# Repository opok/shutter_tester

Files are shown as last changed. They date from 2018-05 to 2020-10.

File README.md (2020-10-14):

# shutter_tester
Arduino camera focal plane shutter speed tester

Circuit uses Arduino Nano 5V and its internal pullup resistor.
2 phototransistors are connected between D2 and GND, and second between D3 and GND.
D2 and D3 because hardware interrupts are available on those pins.

Digital input pin is set to HIGH, but when light hits phototransistor, 
that pulls the volatage of the pin to the ground so reading of the pin returns LOW.
I use interrupts to capture the exact moment the pin is pulled low or goes high.
In interrupt handler routine only the microsecond time is saved.

1604 a.k.a. 16 x 4 character LCD is connected via I2C by 4 wires: SDA, SCL and power supply 5V and GND.

The output on LCD shows exposure time for each sensor as well as curtain travel time of curtain extrapolated to 36mm frame witdth.
My sensors (phototransistors) are 30x20mm apart, positioned diagonally for measuring horizontal as well as vertical shutter,
so the travel time is multiplied by 1.2 to give result for 36mm or 24mm travel.

uses https://github.com/JChristensen/Timer v2 library
https://bitbucket.org/fmalpartida/new-liquidcrystal for LCD via I2C

To find the address of your I2C LCD, use I2C scanner from https://github.com/todbot/SoftI2CMaster (also part of New Liquid Crystal library)

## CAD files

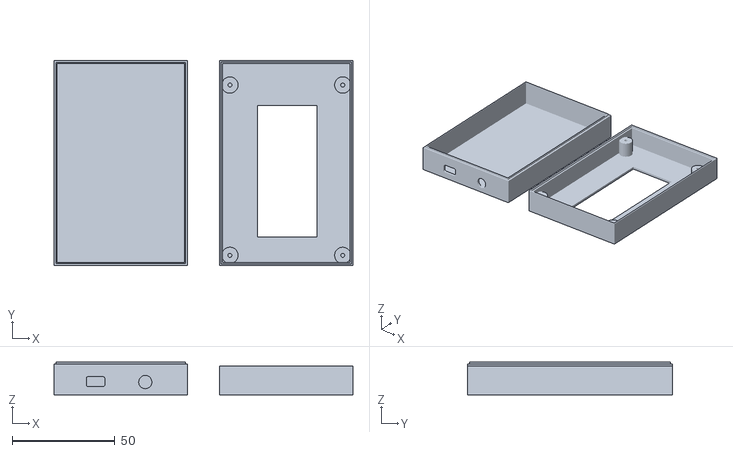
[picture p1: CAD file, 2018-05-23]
Shutter tester box for LCD + Arduino Nano.stl
145.8 x 100.0 x 16.0

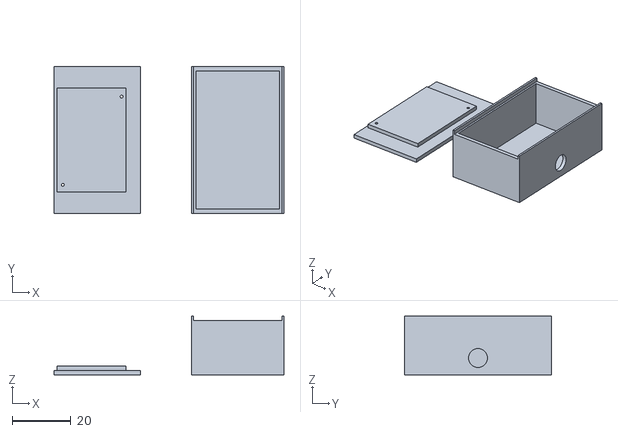
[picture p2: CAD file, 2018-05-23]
Shutter tester probe with own box.stl
78.2 x 50.0 x 20.0

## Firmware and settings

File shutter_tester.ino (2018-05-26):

/*
 * @author Ondrej Pok
 * @version 2.2
 *
 * Arduino camera focal plane shutter speed tester
 *
 * Circuit uses Arduino Nano 5V and its internal pullup resistor.
 * 2 phototransistors are connected between D2 and GND, and second between D3 and GND.
 * D2 and D3 because hardware interrupts are available on those pins.
 *
 * Digital input pin is set to HIGH, but when light hits phototransistor, 
 * that pulls the volatage of the pin to the ground so reading of the pin returns LOW.
 * I use interrupts to capture the exact moment the pin is pulled low or goes high.
 * In interrupt handler routine only the microsecond time is saved.
 *
 * 1604 a.k.a. 16 x 4 character LCD is connected via I2C by 4 wires: SDA, SCL and power supply 5V and GND.
 *
 * The output on LCD shows exposure time for each sensor as well as curtain travel time from sensor 1 to sensor 2.
 * My sensors (phototransistors) are 30x20mm apart, positioned diagonally for measuring horizontal as well as vertical shutter,
 * so the travel time is multiplied by 1.2 to give result for 36mm or 24mm travel.
 *
 * uses https://github.com/JChristensen/Timer v2 library
 * https://bitbucket.org/fmalpartida/new-liquidcrystal for LCD via I2C
 *
 * To find the address of your I2C LCD, use I2C scanner from https://github.com/todbot/SoftI2CMaster (also part of New Liquid Crystal library)
 */

#include <avr/io.h>
#include <avr/interrupt.h>
#include <Wire.h>
#include <LCD.h>
#include <Timer.h>
#include <LiquidCrystal_I2C.h>

#define SENSOR_1 2
#define SENSOR_2 3

#define I2C_ADDR       0x3f
#define BACKLIGHT_PIN  3
#define En_pin  2
#define Rw_pin  1
#define Rs_pin  0
#define D4_pin  4
#define D5_pin  5
#define D6_pin  6
#define D7_pin  7

#define ONE_SECOND 1000000

#define HOLE_X_DISTANCE 30 // keep in mind that hole_Y_distance = hole_X_distance * 24 / 36
#define HOLE_DIAMETER 1.0

// I measured the travel using simpler probe connected to PC sound card and Audacity
// and the tester was giving lot shorter times, so this constant is to compensate.
// Ideally this would be adjusted after comparing results with factory calibrated shutter tester.
#define TRAVEL_CORR_COEF 1.15

// see computation of exposure1 in onDataReady()
// This is to compensate for the simple fact that the transistor 
// doesn't open as soon as curtain edge crosses edge of hole.
// It takes a little bit of opening of the hole to let through enough light 
// to open the transistor - let's say 20% of hole diameter. Same for closing curtain
// the transistor closes before the closing curtain completely closes the hole 
// when the amount of light drops enough. This again may be 20%. So we only need 
// to subtract 60% of the hole diameter from raw exposure measurement.
#define HOLE_SIZE_CORR_COEF 0.6

// if you flip the probe, so S2 is exposed before S1 (S2->S1)
// and the average of several measurements significantly differ from the position (S1->S2)
// then one of these values needs to be adjusted
#define S1_CORR_COEF 1.0
#define S2_CORR_COEF 1.0


LiquidCrystal_I2C lcd (I2C_ADDR,En_pin,Rw_pin,Rs_pin,D4_pin,D5_pin,D6_pin,D7_pin);

// data storage
// 1st item is when sensor was uncovered and light started hitting the phototransistor
// 2nd item is when sensor was covered again
volatile unsigned long s1[2] = {0, 0}, s2[2] = {0, 0};

volatile bool dataReady = false;

Timer timer;


void resetMeasuredData(void *context) {
  Serial.println("resetting data...");
  s1[0] = 0;
  s1[1] = 0;
  s2[0] = 0;
  s2[1] = 0;
  dataReady = false;
  initInterrupts();
}

void printRightAlignedMs(int row, unsigned long microseconds) {
  int whole = microseconds/1000; // whole part from microseconds to miliseconds
  int decimal = (microseconds % 1000) / 10; // 2 decimal digits
  if(whole > 0)
    lcd.setCursor(10 - floor(log10(whole)), row); // how many digits ?
  else
    lcd.setCursor(10, row); // e.g. 0.12ms
  lcd.print(whole, DEC);
  lcd.print('.');
  if(decimal < 10) lcd.print('0');
  lcd.print(decimal, DEC);
  lcd.print("ms");
}

void printExposure(int row, String description, unsigned long exposure) {
  lcd.setCursor(0, row);
  lcd.print("                "); // clear
  lcd.setCursor(0, row);
  lcd.print(description); lcd.print(" ");

  if(exposure < ONE_SECOND) {
    lcd.print("1/"); lcd.print(round(1.0/((double)exposure/ONE_SECOND)), DEC);  
  }
  printRightAlignedMs(row, exposure);
}

void printTravel(int row, String description, unsigned long travel) {
  lcd.setCursor(0, row);
  lcd.print("                ");
  lcd.setCursor(0, row);
  lcd.print(description); lcd.print(" ");

  printRightAlignedMs(row, travel);
}

void onDataReady() {
  Serial.println("onDataReady");
  unsigned long exposure1, exposure2, travel1, travel2, exp1raw, exp2raw, travel1raw, travel2raw;

  travel1raw = max(s1[0], s2[0]) - min(s1[0], s2[0]);
  travel2raw = max(s2[1], s1[1]) - min(s2[1], s1[1]);
  // sensors approx. 20x30mm apart, extrapolate to 24 or 36mm
  travel1 = TRAVEL_CORR_COEF * (36/HOLE_X_DISTANCE) * travel1raw;
  travel2 = TRAVEL_CORR_COEF * (36/HOLE_X_DISTANCE) * travel2raw;

  exp1raw = s1[1] - s1[0];
  exp2raw = s2[1] - s2[0];
  // for measuring exposure the light starts to shine on sensor 
  // when the opening curtain crosses the left edge of the hole
  // but we measure the end of exposure when the light stops shining on the sensor 
  // and that is after closing curtain crosses right edge of the hole
  // Therefore to compensate for the size of the sensor hole
  // we need to subtract the time that takes the closing curtain to travel across the hole
  exposure1 = S1_CORR_COEF * (exp1raw - HOLE_SIZE_CORR_COEF * HOLE_DIAMETER * travel2 / 36);
  exposure2 = S2_CORR_COEF * (exp2raw - HOLE_SIZE_CORR_COEF * HOLE_DIAMETER * travel2 / 36);

  Serial.print("Exposure S1 "); Serial.println(exposure1);
  Serial.print("Exposure S2 "); Serial.println(exposure2);
  Serial.print("Travel opening "); Serial.println(travel1);
  Serial.print("Travel closing "); Serial.println(travel2);
  
  printExposure(0, "E1", exposure1);
  printExposure(1, "E2", exposure2);
  printTravel(2, "Open", travel1);
  printTravel(3, "Close", travel2);

  timer.after(1000, resetMeasuredData, (void*)0);
}

void s1_down() {
  unsigned long measuredValue = micros();
  if(dataReady) { return; }
  if(s1[0] == 0){
    s1[0] = measuredValue;
  }
  detachInterrupt(digitalPinToInterrupt(SENSOR_1));
  attachInterrupt(digitalPinToInterrupt(SENSOR_1), s1_up, RISING);

  //timer to stop waiting for more signals and to reset interrupts after ~2 seconds
  timer.after(2000, resetMeasuredData, (void*)0);
}

void s1_up() {
  unsigned long measuredValue = micros();
  if(dataReady) { return; }
  if(s1[1] == 0)
    s1[1] = measuredValue;
  detachInterrupt(digitalPinToInterrupt(SENSOR_1));
}

void s2_down() {
  unsigned long measuredValue = micros();
  if(dataReady) { return; }
  if(s2[0] == 0)
    s2[0] = measuredValue;
  detachInterrupt(digitalPinToInterrupt(SENSOR_2));
  attachInterrupt(digitalPinToInterrupt(SENSOR_2), s2_up, RISING);
}

void s2_up() {
  unsigned long measuredValue = micros();
  if(dataReady) { return; }
  if(s2[1] == 0)
    s2[1] = measuredValue;
  detachInterrupt(digitalPinToInterrupt(SENSOR_2));
}

void initInterrupts() {
  detachInterrupt(digitalPinToInterrupt(SENSOR_1));
  detachInterrupt(digitalPinToInterrupt(SENSOR_2)); 
  EIFR = 0x03; // reset interrupt register
  attachInterrupt(digitalPinToInterrupt(SENSOR_1), s1_down, FALLING);
  attachInterrupt(digitalPinToInterrupt(SENSOR_2), s2_down, FALLING);
}



void setup()
{
  Serial.begin(9600);
  Serial.println("setting up...");
  
  lcd.begin(16,4);
  lcd.setBacklightPin(BACKLIGHT_PIN,NEGATIVE);

  // set input pins HIGH
  digitalWrite(SENSOR_1, HIGH);
  digitalWrite(SENSOR_2, HIGH);
  
  initInterrupts();
}

void loop()
{
  timer.update();
  
  if(!dataReady && s1[0] != 0 && s1[1] != 0 && s2[0] != 0 && s2[1] != 0) {
    dataReady = true;
    onDataReady();
  }
}

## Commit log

2018-05-23 performance tweak and improved LCD output
    - remove serial print from inside of interrupt handler
    - improve LCD output - now LCD uses 4 rows to display these values:
    - exposure of sensor 1 as fraction and in miliseconds e.g. "E1 1/50 20.00ms"
    - travel time of opening and closing curtain e.g. "Open 12.34ms"
2018-05-23 revert back the file description comment
    [shutter_tester.ino]
2018-05-23 add 3D model files for the boxes
    [Shutter tester box for LCD + Arduino Nano.stl, Shutter tester probe with own box.stl]
2018-05-23 fix display of exposure < 1ms
    [shutter_tester.ino]
2018-05-26 add correction coeficient constants
    [shutter_tester.ino]
